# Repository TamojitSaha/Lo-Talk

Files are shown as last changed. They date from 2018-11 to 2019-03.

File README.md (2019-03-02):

<h1 align="center">Lo-Talk</h1>

# About



Lo-Talk is an open-hardware ISM band off-grid communicator based on Nordic's NRF51822 and Semtech's LoRa module on SX1278. This device can be helpful in node to node communication and mesh networking over the ISM band and has hardware support for SOS alerts.
The device communication range was tested upto 500mm in an urban area without line of sight and maximum Tx Power 0.3W.

# Schematic
<p align="center">
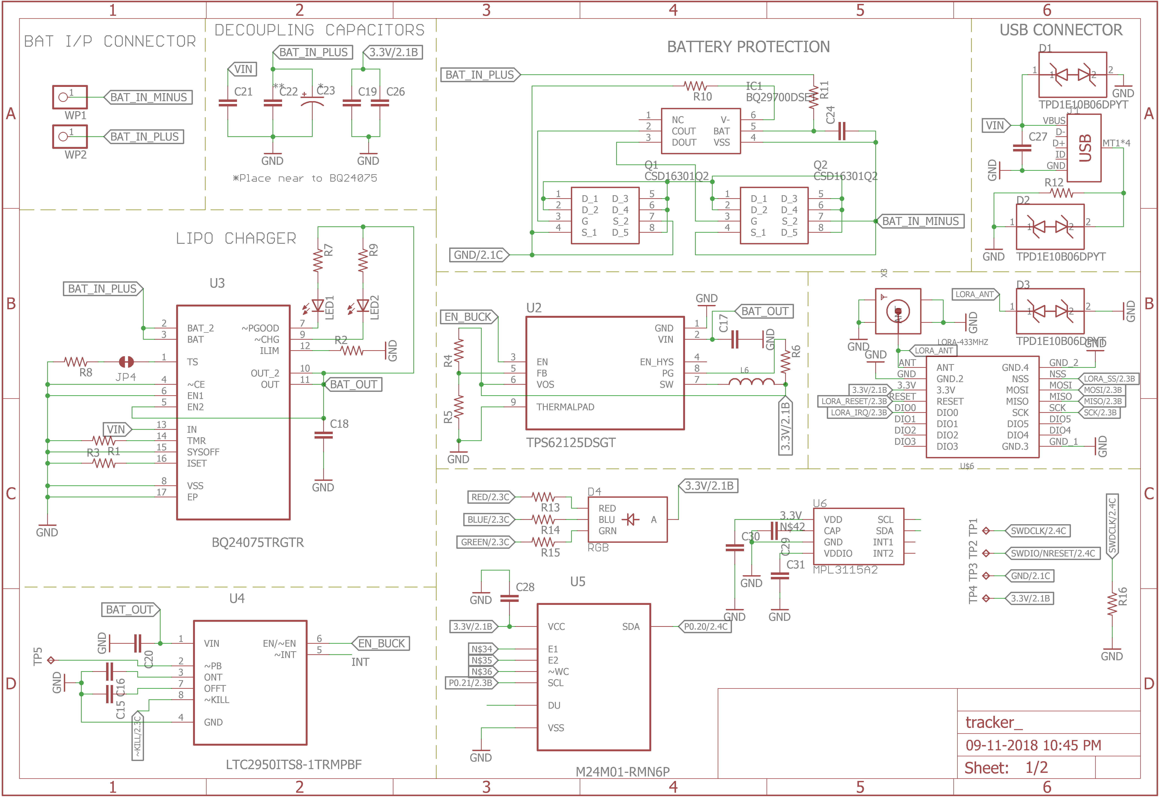
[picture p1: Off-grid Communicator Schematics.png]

</p>

# Layout
<p align="center">
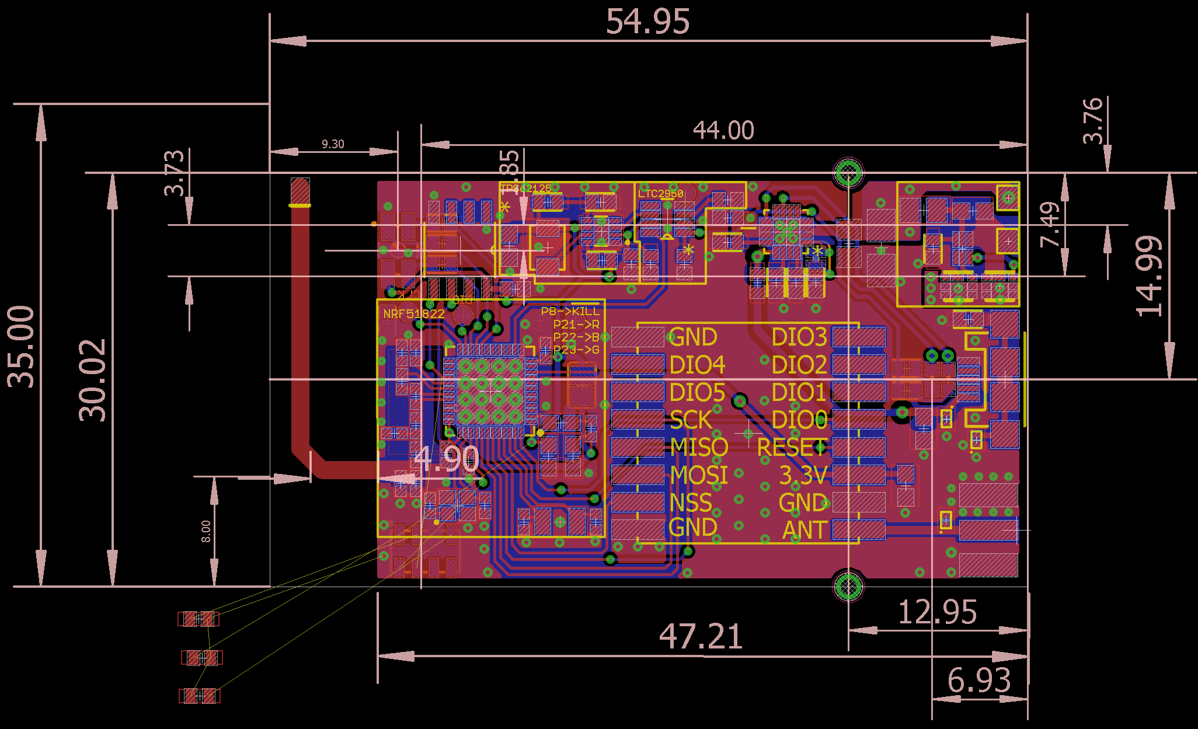
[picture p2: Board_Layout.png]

</p>

# License
The source files are released under  [Creative Commons Attribution-NonCommercial-NoDerivatives 4.0 International License](http://creativecommons.org/licenses/by-nc-nd/4.0/) .

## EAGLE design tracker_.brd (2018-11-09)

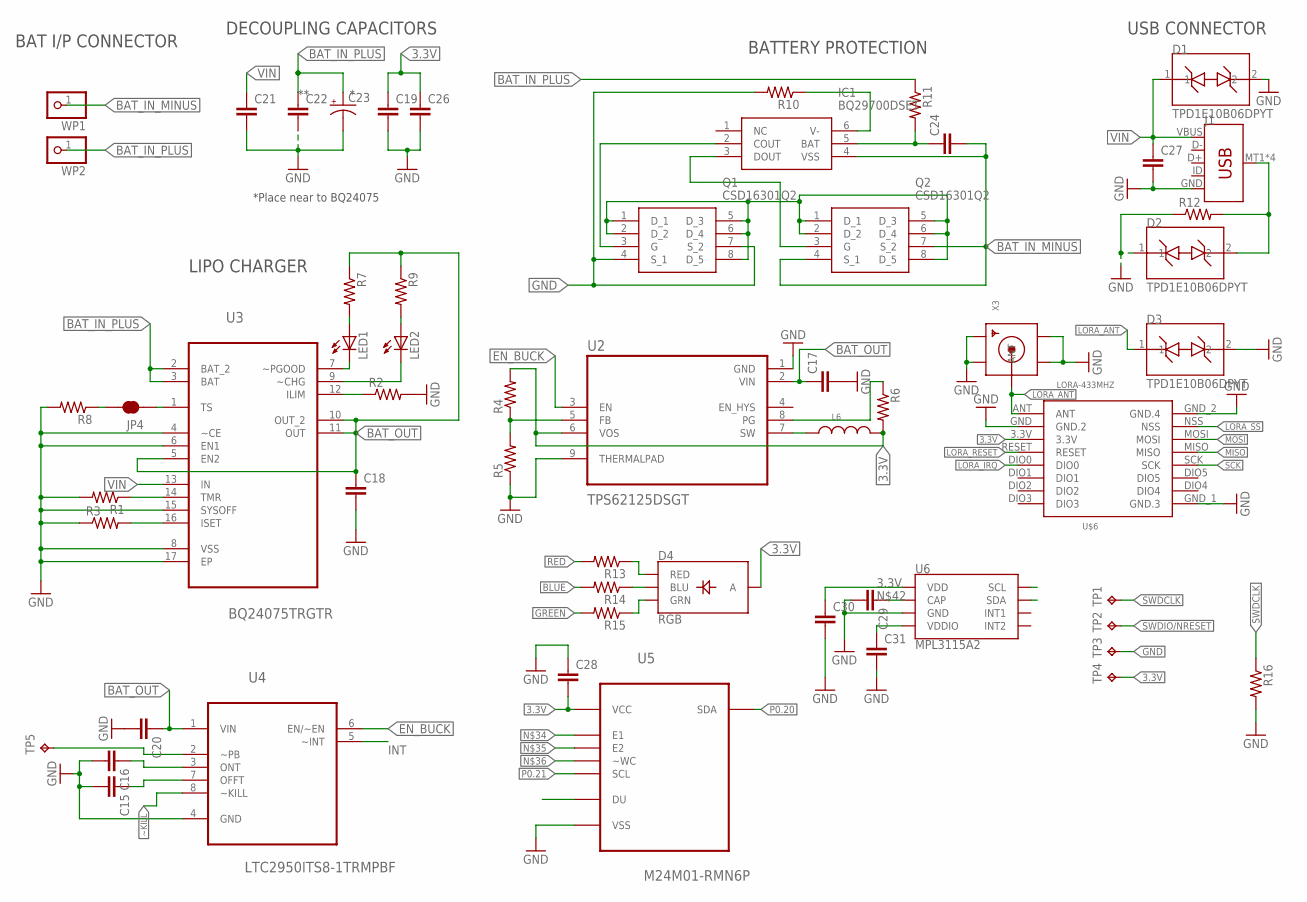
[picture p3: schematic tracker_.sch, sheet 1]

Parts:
C15, C16, C17, C18, C20, C21, C28, C29, C30, C31: C-EUC0402; C0402
C19, C24, C26, C27: C-EUC0603; C0603
C22: C-EUC0805K; C0805K
C23: CPOL-USB/3528-21W; B/3528-21W
D1, D2, D3: TPD1E10B06DPYT; DFN100X60X45-2N
D4: RGB; P-LCC-4-3
IC1: BQ29700DSET; SON50P150X150X80-6N
J1: USB_MICRO-B_SMT; USB-MICROB
JP4: JUMPER-SMT_2_NC_TRACE_SILK; SMT-JUMPER_2_NC_TRACE_SILK
L6: WE-GF_1210(M)_744764115; WE-GF_1210
LED1, LED2: LEDCHIPLED_0603; CHIPLED_0603
Q1, Q2: CSD16301Q2
R1, R2, R3, R4, R5, R6, R7, R8, R9, R10, R12, R13, R14, R15, R16: R-US_R0402; R0402
R11: R-US_M0805; M0805
TP1, TP2, TP3, TP4, TP5: TPB1,27; B1,27
U2: TPS62125DSGT; SON50P200X200X80-9N
U3: BQ24075TRGTR; QFN50P300X300X100-17N
U4: LTC2950ITS8-1TRMPBF; SOT65P280X100-8N
U5: M24M01-RMN6P; SOIC127P600X175-8N
U6: MPL3115A2; LGA-8-5X3
U$6: LORA-433MHZ; LORA-RA1-SMD
WP1, WP2: WPAD-1-0805
X3: SMACONNECTOR_EDGE; SMA_EDGELAUNCH

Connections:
3.3V: C19.1, C26.1, C28.2, C30.1, D4.4 (A), L6.2, R4.2, R6.2, TP4.TP, U2.6 (VOS), U5.8 (VCC), U6.1 (VDD), U$6.3.3V; also elsewhere on the board
BAT_IN_MINUS: C24.2, IC1.4 (VSS), Q2.4 (S_1), Q2.7 (S_2), WP1.1
BAT_IN_PLUS: C22.1, C23.+, R11.1, U3.2 (BAT_2), U3.3 (BAT), WP2.1
BAT_OUT: C17.1, C18.1, C20.1, R7.1, R9.1, U2.2 (VIN), U3.5 (EN2), U3.10 (OUT_2), U3.11 (OUT), U4.1 (VIN)
BLUE: R14.2; also elsewhere on the board
DRAIN: Q1.1 (D_1), Q1.2 (D_2), Q1.5 (D_3), Q1.6 (D_4), Q1.8 (D_5), Q2.1 (D_1), Q2.2 (D_2), Q2.5 (D_3), Q2.6 (D_4), Q2.8 (D_5)
EN_BUCK: U2.3 (EN), U4.6 (EN/~EN)
GND: C15.2, C16.2, C17.2, C18.2, C19.2, C20.2, C21.2, C22.2, C23.-, C26.2, C27.2, C28.1, C29.2, C30.2, C31.2, D1.2, D2.1, D3.2, J1.GND, Q1.4 (S_1), Q1.7 (S_2), R1.2, R2.2, R3.1, R5.1, R8.2, R10.2, R12.1, R16.2, TP3.TP, U2.1 (GND), U2.9 (THERMALPAD), U3.4 (~CE), U3.6 (EN1), U3.8 (VSS), U3.15 (SYSOFF), U3.17 (EP), U4.4 (GND), U5.4 (VSS), U6.3 (GND), U$6.GND (GND.2), U$6.GND_1 (GND.3), U$6.GND_2 (GND.4), X3.GND@1 (GND4), X3.GND@2 (GND3), X3.GND@3 (GND2), X3.GND@4 (GND1); also elsewhere on the board
GREEN: R15.2; also elsewhere on the board
INT: U4.5 (~INT)
LORA_ANT: D3.1, U$6.ANT, X3.P (ANT)
LORA_IRQ: U$6.DIO0; also elsewhere on the board
LORA_RESET: U$6.RESET; also elsewhere on the board
LORA_SS: U$6.NSS; also elsewhere on the board
MISO: U$6.MISO; also elsewhere on the board
MOSI: U$6.MOSI; also elsewhere on the board
unnamed: R1.1, U3.14 (TMR)
unnamed: R3.2, U3.16 (ISET)
unnamed: R2.1, U3.12 (ILIM)
unnamed: R4.1, R5.2, U2.5 (FB)
unnamed: LED1.C, U3.7 (~PGOOD)
unnamed: LED2.C, U3.9 (~CHG)
unnamed: LED1.A, R7.2
unnamed: LED2.A, R9.2
unnamed: IC1.2 (COUT), Q1.3 (G)
unnamed: IC1.3 (DOUT), Q2.3 (G)
unnamed: D2.2, J1.MT1 (SHIELD), J1.MT2 (SHIELD), J1.P$1 (SHIELD), J1.P$2 (SHIELD), R12.2
unnamed: D4.1 (RED), R13.1
unnamed: R6.1, U2.8 (PG)
unnamed: JP4.1, U3.1 (TS)
unnamed: D4.3 (BLU), R14.1
unnamed: JP4.2, R8.1
unnamed: IC1.6 (V-), R10.1
unnamed: C16.1, U4.3 (ONT)
unnamed: C15.1, U4.7 (OFFT)
unnamed: C24.1, IC1.5 (BAT), R11.2
unnamed: D4.2 (GRN), R15.1
unnamed: TP5.TP, U4.2 (~PB)
unnamed: C29.1, U6.2 (CAP)
unnamed: C31.1, U6.4 (VDDIO)
P0.20: U5.5 (SDA), U6.7 (SDA); also elsewhere on the board
P0.21: U5.6 (SCL), U6.8 (SCL); also elsewhere on the board
RED: R13.2; also elsewhere on the board
SCK: U$6.SCK; also elsewhere on the board
SW: L6.1, U2.7 (SW)
SWDCLK: R16.1, TP1.TP; also elsewhere on the board
SWDIO/NRESET: TP2.TP; also elsewhere on the board
VIN: C21.1, C27.1, D1.1, J1.VBUS, U3.13 (IN)
~KILL: U4.8 (~KILL); also elsewhere on the board

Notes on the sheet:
BAT I/P CONNECTOR
*Place near to BQ24075
DECOUPLING CAPACITORS
LIPO CHARGER
BATTERY PROTECTION
USB CONNECTOR

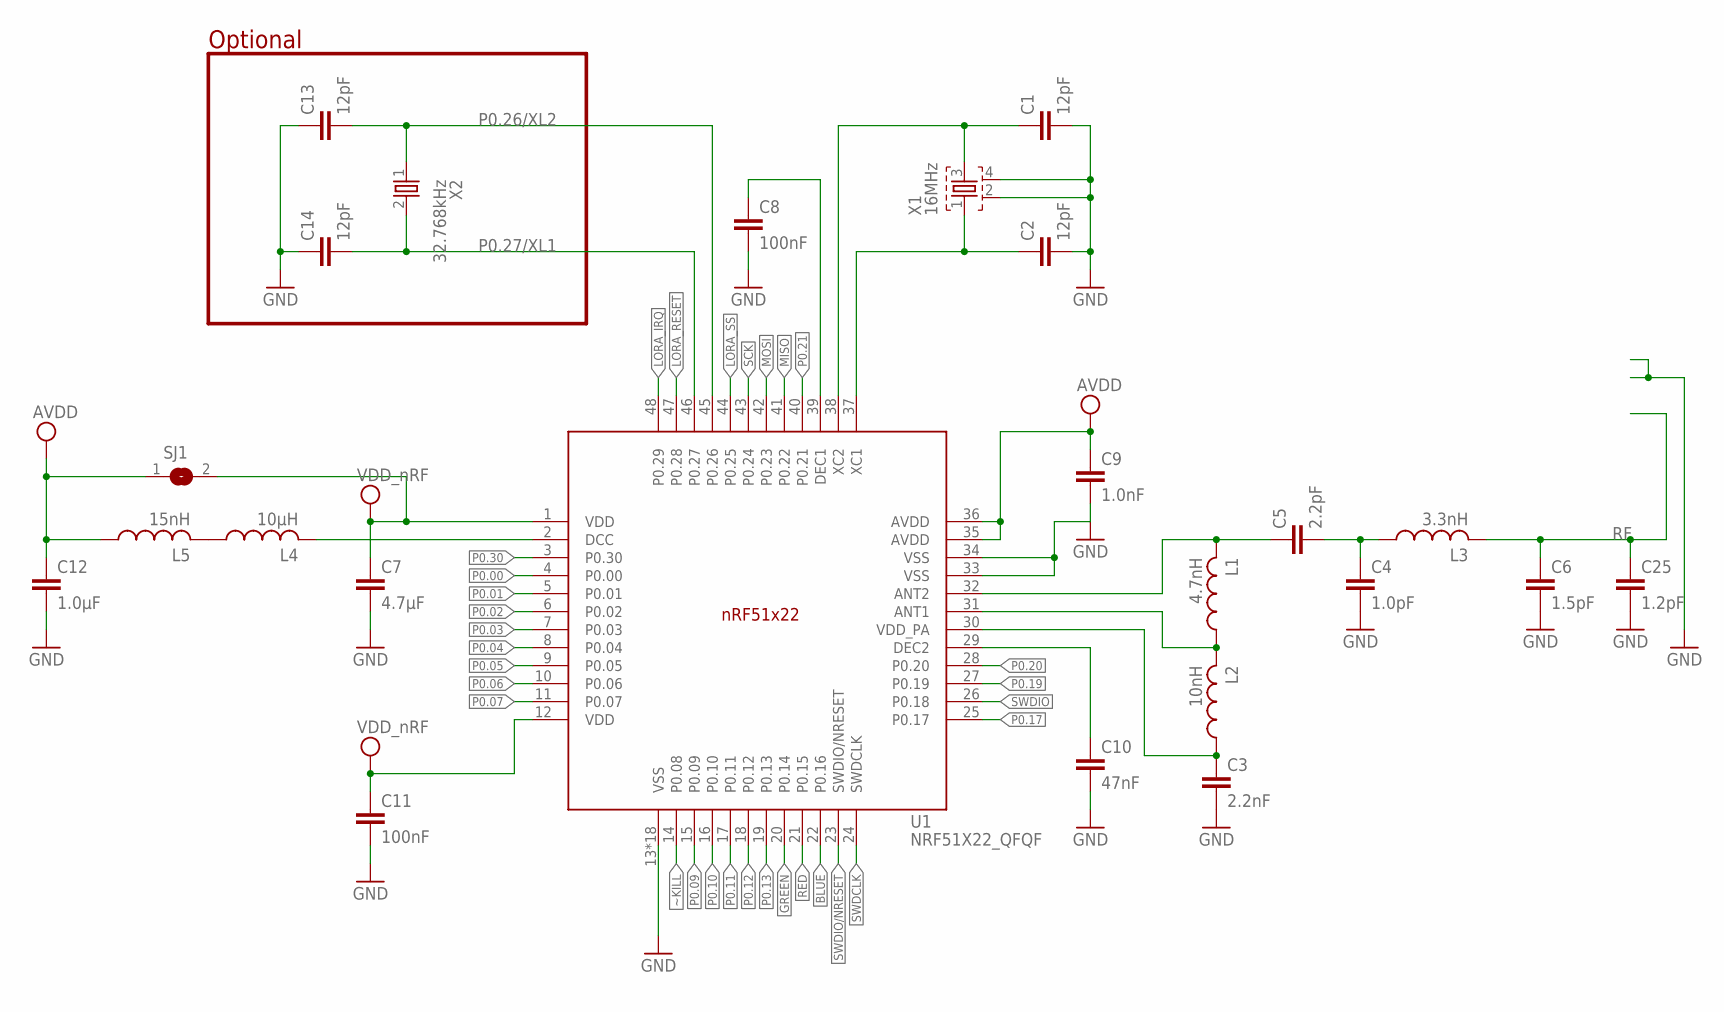
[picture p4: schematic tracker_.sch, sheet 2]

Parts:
C1, C2, C13, C14: 12pF; RESC0402_N
C3: 2.2nF; RESC0402_N
C4: 1.0pF; RESC0402_N
C5: 2.2pF; RESC0402_N
C6: 1.5pF; RESC0402_N
C7: 4.7µF; RESC0603_N
C8, C11: 100nF; RESC0402_N
C9: 1.0nF; RESC0402_N
C10: 47nF; RESC0402_N
C12: 1.0µF; RESC0603_N
C25: 1.2pF; RESC0402_N
L1: 4.7nH; RESC0402_N
L2: 10nH; RESC0402_N
L3: 3.3nH; RESC0402_N
L4: 10µH; RESC0603_N
L5: 15nH; RESC0402_N
SJ1: SJ
U1: NRF51X22_QFQF; QFN40P600X600X90-48_N
X1: 16MHz; BT-XTAL_2016_N
X2: 32.768kHz; XTAL_3215_N

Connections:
3.3V: C7.1, C11.1, SJ1.2, U1.1 (VDD), U1.12 (VDD); also elsewhere on the board
AVDD: C9.1, C12.1, L5.1, SJ1.1, U1.35 (AVDD), U1.36 (AVDD)
BLUE: U1.22 (P0.16); also elsewhere on the board
GND: C1.2, C2.2, C3.2, C4.2, C6.2, C7.2, C8.2, C9.2, C10.2, C11.2, C12.2, C13.1, C14.1, C25.2, U1.13 (VSS), U1.33 (VSS), U1.34 (VSS), U1.PAD (VSS), U1.PAD@VIA01 (VSS), U1.PAD@VIA02 (VSS), U1.PAD@VIA03 (VSS), U1.PAD@VIA04 (VSS), U1.PAD@VIA05 (VSS), U1.PAD@VIA06 (VSS), U1.PAD@VIA07 (VSS), U1.PAD@VIA08 (VSS), U1.PAD@VIA09 (VSS), U1.PAD@VIA10 (VSS), U1.PAD@VIA11 (VSS), U1.PAD@VIA12 (VSS), U1.PAD@VIA13 (VSS), U1.PAD@VIA14 (VSS), U1.PAD@VIA15 (VSS), U1.PAD@VIA16 (VSS), X1.2, X1.4; also elsewhere on the board
GREEN: U1.20 (P0.14); also elsewhere on the board
LORA_IRQ: U1.48 (P0.29); also elsewhere on the board
LORA_RESET: U1.47 (P0.28); also elsewhere on the board
LORA_SS: U1.44 (P0.25); also elsewhere on the board
MISO: U1.41 (P0.22); also elsewhere on the board
MOSI: U1.42 (P0.23); also elsewhere on the board
unnamed: L1.1, L2.2, U1.31 (ANT1)
unnamed: L4.1, L5.2
unnamed: C1.1, U1.38 (XC2), X1.3
unnamed: L4.2, U1.2 (DCC)
unnamed: C10.1, U1.29 (DEC2)
unnamed: C8.1, U1.39 (DEC1)
unnamed: C3.1, L2.1, U1.30 (VDD_PA)
unnamed: C5.1, L1.2, U1.32 (ANT2)
unnamed: C4.1, C5.2, L3.1
P0.00: U1.4 (P0.00)
P0.01: U1.5 (P0.01)
P0.02: U1.6 (P0.02)
P0.03: U1.7 (P0.03)
P0.04: U1.8 (P0.04)
P0.05: U1.9 (P0.05)
P0.06: U1.10 (P0.06)
P0.07: U1.11 (P0.07)
P0.09: U1.15 (P0.09)
P0.10: U1.16 (P0.10)
P0.11: U1.17 (P0.11)
P0.12: U1.18 (P0.12)
P0.13: U1.19 (P0.13)
P0.17: U1.25 (P0.17)
P0.19: U1.27 (P0.19)
P0.20: U1.28 (P0.20); also elsewhere on the board
P0.21: U1.40 (P0.21); also elsewhere on the board
P0.26/XL2: C13.2, U1.45 (P0.26), X2.1
P0.27/XL1: C14.2, U1.46 (P0.27), X2.2
P0.30: U1.3 (P0.30)
RED: U1.21 (P0.15); also elsewhere on the board
RF: C6.1, C25.1, L3.2
SCK: U1.43 (P0.24); also elsewhere on the board
SWDCLK: U1.24 (SWDCLK); also elsewhere on the board
SWDIO: U1.26 (P0.18)
SWDIO/NRESET: U1.23 (SWDIO/NRESET); also elsewhere on the board
X1: C2.1, U1.37 (XC1), X1.1
~KILL: U1.14 (P0.08); also elsewhere on the board

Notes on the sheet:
Optional

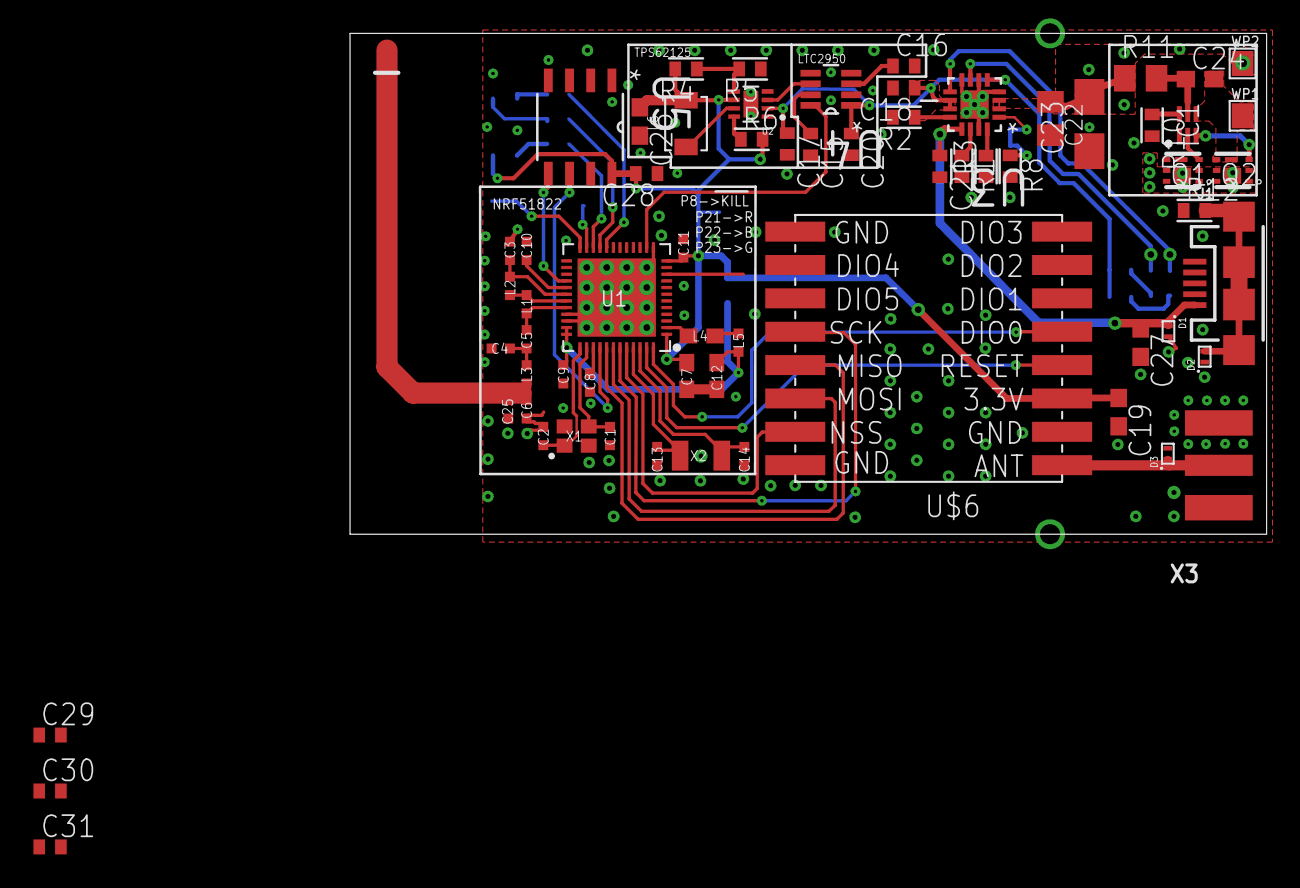
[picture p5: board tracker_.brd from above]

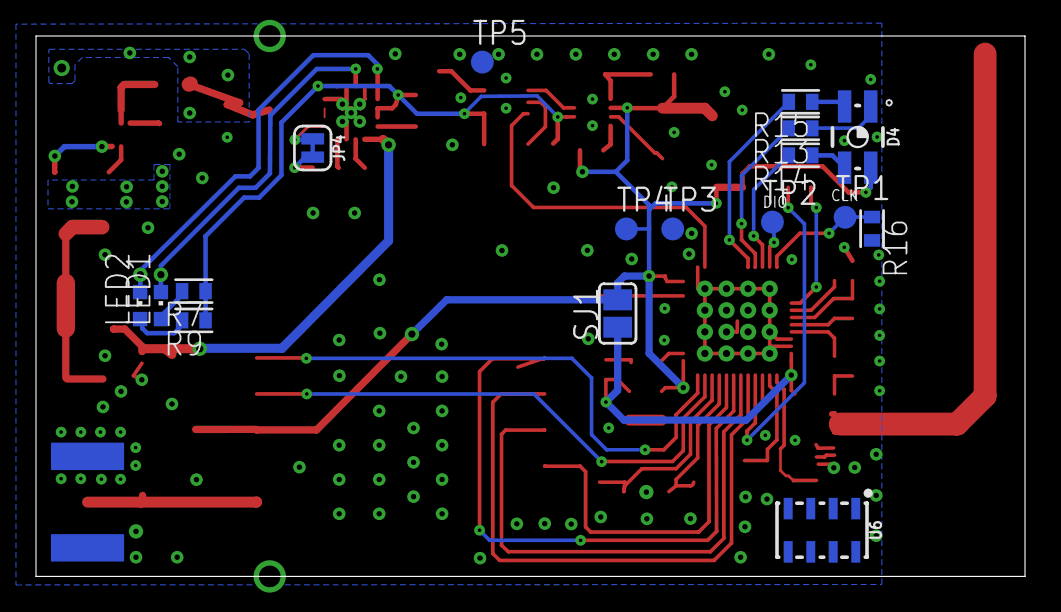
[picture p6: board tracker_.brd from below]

Board: 2 copper layers, 54.9 x 30.0 mm, 82 parts (17 on the bottom side), 62 nets.

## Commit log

2018-11-09 Added EagleCAD source files
    [tracker_.brd, tracker_.sch]
2018-11-09 Added schematic png
2018-11-09 Added Board layout

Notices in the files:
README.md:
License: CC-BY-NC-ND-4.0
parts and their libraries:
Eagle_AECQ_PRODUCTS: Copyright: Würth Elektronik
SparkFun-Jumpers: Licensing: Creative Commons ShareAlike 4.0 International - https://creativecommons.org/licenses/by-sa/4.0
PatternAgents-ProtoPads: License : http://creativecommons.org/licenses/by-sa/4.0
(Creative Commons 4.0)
